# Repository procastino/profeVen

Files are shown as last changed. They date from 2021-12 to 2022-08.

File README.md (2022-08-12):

# profeVen
## What is this?
A little Arduino indicator for computer science class management. It must be placed on a visible spot on the student's table. It has an RGB LED and two pushbuttons, start and reset. When you press button start, led lights, indicating that the student needs the teacher (profe) to come (ven) and help him/her. Every while (1 minute by default), if the teacher has not attended the student demand, light will change color according to the sequence purple - cyan - blue - yellow - red, so that the teacher knows who has been waiting the most. When the light gets red, it stays there. When teacher solves the student's problem, presses reset button to turn light off. If the student has finished his work and wants to let the teacher know that he is ready to go on, he can long press the start button and a green light will start to fade out and in.
## (Not so) technicals
This device is controlled by an atTiny85, and powered by an USB connection. It has a custom PCB designed in KiCad and it's enclosure is designed in the openSCad files. The "lid" part must be printed with transparent or translucid plastic.
Programming is written in Arduino, surely it's not great code, but it gets the job done.
## Disclaimer
It is a quite overengineered solution for managing classrooms, you can obviously find simpler ways of dealing with your students doubts. But I teach design and technology, so... what did you expect?

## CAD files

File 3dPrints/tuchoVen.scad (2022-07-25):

//These are the pieces for a enclosure for the profeVen class management beacon. It's got a base, a lid and two buttons.

//parameters
side = 43.180;
roundCorner = 2.54;
screwHoleRadius = 1.5;
throughHoleRadius = 1.6;
wallThickness = 2;
baseHeight= 14;
$fn = 20;
buttonHoleRadius = 5;
pushButtonHeight = 5.5; //this is the height of the push Button, higher pcb buttons, shorter printed buttons.
xPosButtonHoleStart = 21.336;
yPosButtonHoleStart = 5.588;

xPosButtonHoleReset = 7.112;
yPosButtonHoleReset = 18.796;
connectorHole = 15.240;

//All the pieces/////
base();
translate ([side*1.6,0,0]) lid();
translate([0,side*1.5,0]) buttons();
//////////////

//base
//it's a difference between two rounded corner boxes plus some things
module base(){
    difference(){
        extBox();
        translate([0,0,wallThickness])pcbHole();
        //cable hole
        translate ([11,side,baseHeight-2.5]) cube([3,6,3]);
    }
    pcbStands();
    translate([-roundCorner*1.6,side/2,baseHeight/2])baseMountStands();
    translate([side+roundCorner*1.6,side/2,baseHeight/2])rotate([0,0,180]) baseMountStands();
}

//lid
//the same as the base, minus some things
module lid(){
    difference(){
        extBox();
        translate([0,0,wallThickness])pcbHole();
        //hole Button start
        translate([side-xPosButtonHoleStart,yPosButtonHoleStart,-1]) cylinder(r=buttonHoleRadius,h=4);
        //hole Button reset
        translate([side-xPosButtonHoleReset,yPosButtonHoleReset,-1]) cylinder(r=buttonHoleRadius,h=4);
        //hole connector
        translate ([-6,0,baseHeight-2.5]) cube([6,connectorHole,3]);
         //switch Hole
        translate ([side,side/1.5,baseHeight-5]) cube([6,9,6]);
    }
    //baseMount Stands
    translate([-roundCorner*1.6,side/2,baseHeight/2])baseMountStands();
    translate([side+roundCorner*1.6,side/2,baseHeight/2])rotate([0,0,180]) baseMountStands();

}





//button
//simple cylinders with symbols
module buttons(){
    //startButton
    difference(){
        union(){
            cylinder(r=buttonHoleRadius+wallThickness,h=baseHeight-wallThickness-pushButtonHeight);
            cylinder(r=buttonHoleRadius*0.9,h=baseHeight+wallThickness-pushButtonHeight);
            }
        translate([0,0,9]) cylinder(r=buttonHoleRadius/1.5,h=wallThickness,$fn=3);
     }
    //resetButton
   translate([30,0,0]) difference(){
        union(){
            cylinder(r=buttonHoleRadius+wallThickness,h=baseHeight-wallThickness-pushButtonHeight);
            cylinder(r=buttonHoleRadius*0.9,h=baseHeight+wallThickness-pushButtonHeight);
        }
        translate([0,0,9]) cylinder(r=buttonHoleRadius/1.5,h=wallThickness,$fn=4);
   }
}

//exterior box
module extBox(){
    hull(){
        cylinder (r=roundCorner+wallThickness, h = baseHeight);
        translate ([side,0,0]) cylinder (r=roundCorner+wallThickness, h = baseHeight);
        translate ([side,side,0]) cylinder (r=roundCorner+wallThickness, h = baseHeight);
        translate ([0,side,0]) cylinder (r=roundCorner+wallThickness, h = baseHeight);
    }
}

//pcb hole
module pcbHole(){
    hull(){
        cylinder (r=roundCorner, h = 16);
        translate ([side,0,0]) cylinder (r=roundCorner, h = 16);
        translate ([side,side,0]) cylinder (r=roundCorner, h = 16);
        translate ([0,side,0]) cylinder (r=roundCorner, h = 16);
    }
}

//pcb stands
module pcbStands(){
    difference(){
        translate([2.54,2.54,0])cylinder (r=roundCorner+wallThickness, h = baseHeight-1.7);
        translate([2.54,2.54,wallThickness]) cylinder (r=screwHoleRadius, h = baseHeight);
    }
    translate ([side,0,0]) cylinder (r=roundCorner+wallThickness, h = baseHeight-1.7);
    difference(){
        translate ([side-2.54,side-2.54,0]) cylinder (r=roundCorner+wallThickness, h = baseHeight-1.7);
        translate([side-2.54,side-2.54,wallThickness]) cylinder (r=screwHoleRadius, h = baseHeight);
    }
    translate ([0,side,0]) cylinder (r=roundCorner+wallThickness, h = baseHeight-1.7);
}
//base mount stands
module baseMountStands(){
    difference(){
        linear_extrude(height = baseHeight, center = true, convexity = 10, scale=[3.3,1])
        translate ([-1,0,0]) square([2,10],true);
        translate ([-3.6,0,baseHeight-8.8]) cylinder(r=throughHoleRadius,h=baseHeight);
        translate ([-3,0,-2]) cube([6,6,baseHeight],true);
}
}

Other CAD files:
3dPrints/tuchoVenLens.scad

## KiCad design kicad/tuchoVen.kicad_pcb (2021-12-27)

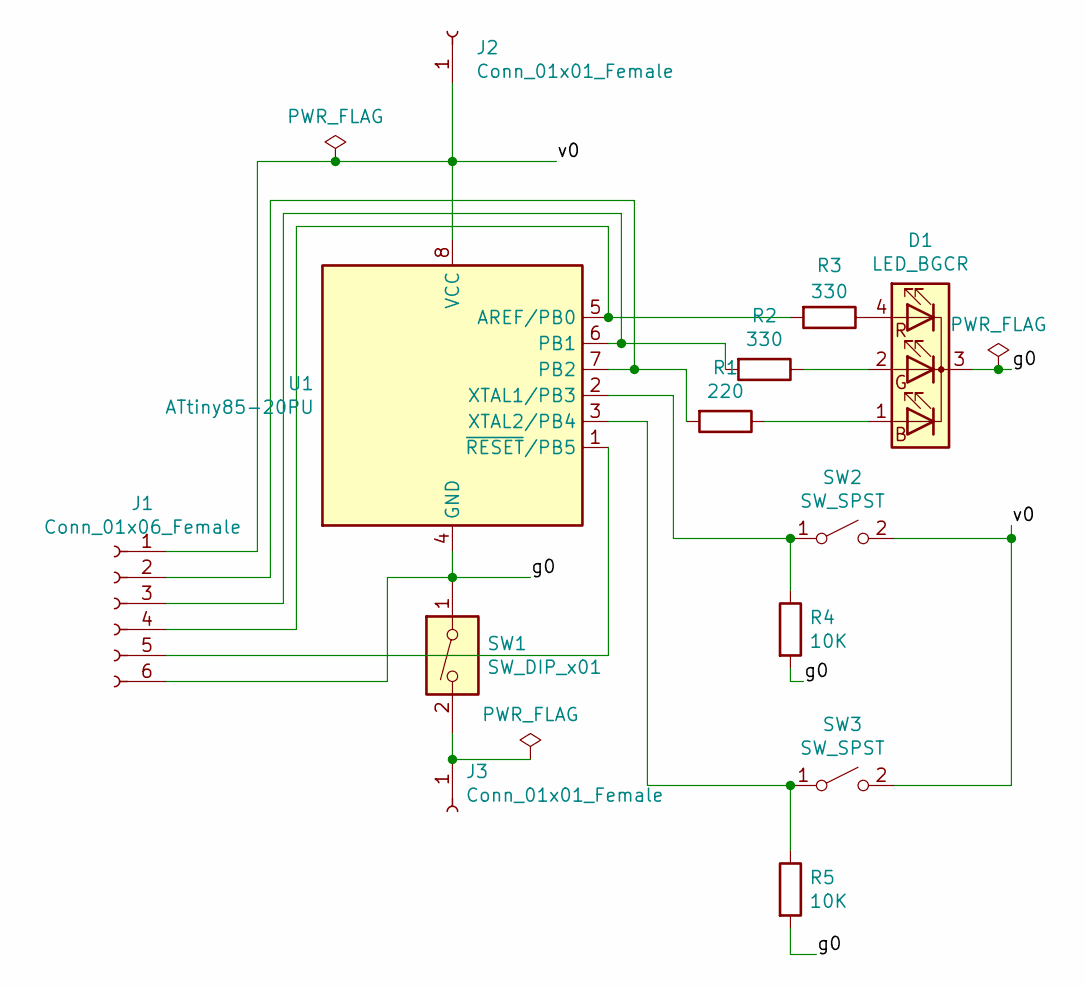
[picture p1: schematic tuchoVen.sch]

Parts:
D1: LED_BGCR; LED_D5.0mm-4_RGB
J1: Conn_01x06_Female; PinHeader_1x06_P2.54mm_Horizontal
J2, J3: Conn_01x01_Female; SolderWire-0.25sqmm_1x01_D0.65mm_OD1.7mm_Relief
R1: 220; R_Axial_DIN0207_L6.3mm_D2.5mm_P7.62mm_Horizontal
R2, R3: 330; R_Axial_DIN0207_L6.3mm_D2.5mm_P7.62mm_Horizontal
R4, R5: 10K; R_Axial_DIN0207_L6.3mm_D2.5mm_P7.62mm_Horizontal
SW1: SW_DIP_x01; SW_CuK_OS102011MA1QN1_SPDT_Angled
SW2, SW3: SW_SPST; SW_PUSH_6mm
U1: ATtiny85-20PU; DIP-8_W7.62mm

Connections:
/g0: D1.3 (K), J1.6, R4.2, R5.2, SW1.1, U1.4 (GND)
/v0: J1.1, J2.1, SW2.2 (B), SW3.2 (B), U1.8 (VCC)
unnamed: D1.1 (BA), R1.1
unnamed: D1.2 (GA), R2.1
unnamed: D1.4 (RA), R3.1
unnamed: J1.2, R1.2, U1.7 (PB2)
unnamed: J1.3, R2.2, U1.6 (PB1)
unnamed: J1.4, R3.2, U1.5 (AREF/PB0)
unnamed: J1.5, U1.1 (~RESET~/PB5)
unnamed: J3.1, SW1.2
unnamed: R4.1, SW2.1 (A), U1.2 (XTAL1/PB3)
unnamed: R5.1, SW3.1 (A), U1.3 (XTAL2/PB4)

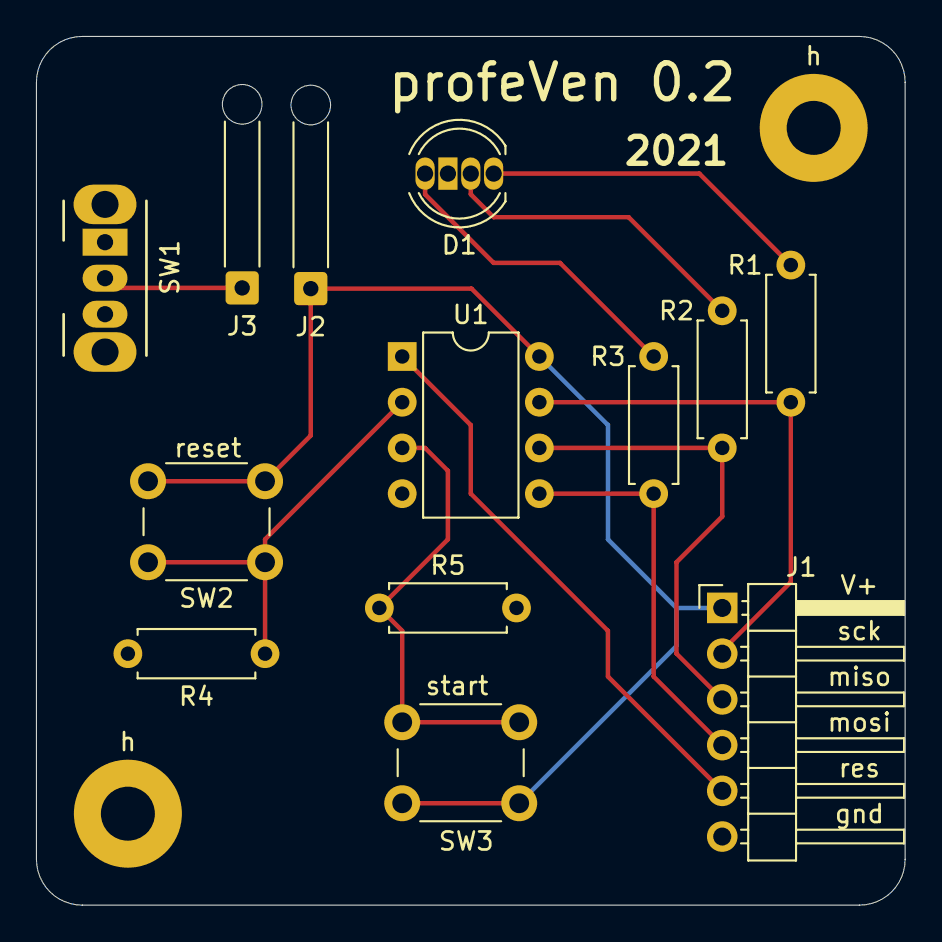
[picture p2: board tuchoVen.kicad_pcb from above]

Board: 2 copper layers, 48.3 x 48.3 mm, 15 parts (0 on the bottom side), 12 nets.

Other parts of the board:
h: MountingHole_3mm_Pad
h#2: MountingHole_3mm_Pad

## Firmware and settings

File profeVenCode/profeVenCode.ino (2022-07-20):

/*proxecto dun dispositivo para chamar ao profesor, para situar enriba do ordenador.
 * cando o alumno preme o botón, acéndese a luz de chamada, que vai cambiando en función do tempo
 * que leva agardando. A luz apágase premendo o botón de reset.
 * Codigo feito para un Attiny85 cun LED RGB con cátodo común, cambiar a lóxica se é de ánodo común en changelight().
 * Ollo, programar co reloxo interno de 1MHz para que os tempo sexan reais
 */

//pins para os leds de cores, dacordo coa PCB do proxecto.
const int pinR = 0;
const int pinG = 1;
const int pinB = 2;
//pins para os botons de reseteo e de chamada
const int buttonReset = 3; //pin 2 fisico
const int buttonStart = 4; //pin 3 fisico
//variables precisas para a xestión do tempo e recollida de estado dos botóns
bool resetState;
bool resetLastState = LOW;
bool startState;
bool startLastState = LOW;
long timeElapsed;
long timeChange = 60000; //cada cantos milisegundos cambia de cor a luz
bool calling = false; //esta chamando o alumno?
bool finished = false; //acabou o traballo o alumno?
int val;
int increment = 1;
int byteLeds = 7; //numero binario que define o estado dos leds 
//secuencia de cores para a funcion de chamado
int colorSequence[] = {2,6,4,1,3}; //purple, blue, cyan, yellow, red
int colorIndex; //valor para seleccionar un elemento da secuencia de cores
int longPressDuration = 2000; //duracion da pulsacion longa
long pressedTime;


void setup() {
  //Modo dos pines
  pinMode (pinR, OUTPUT);
  pinMode (pinG, OUTPUT);
  pinMode (pinB, OUTPUT);
  pinMode (buttonReset, INPUT);
  pinMode (buttonStart, INPUT);
  //actualizamos o estado dos leds
  changeLight();

}

void loop() {
  //lemos boton de reset, apagamos todo se se activou
  resetState = digitalRead(buttonReset);
  if (resetState != resetLastState){
    if (resetState == HIGH){
      byteLeds = 7;//isto define todos os leds como apagados
      changeLight();
      calling = false;
      finished = false;
      resetLastState = HIGH;
    }
    else {
      resetLastState = LOW;
    }
  }

  //lemos boton de start, poñemos en marcha a chamada se se activou
  startState = digitalRead(buttonStart);
  if (startState != startLastState){
    if (startState == HIGH){
      pressedTime = millis();//inciamos o temporizador do intre de pulsacion
      timeElapsed = millis(); //iniciamos o temporizador de tempo transcorrido
      calling = true; //o chamador está a chamar
      finished = false; //non rematou
      colorIndex = 0;
      byteLeds = colorSequence[colorIndex]; // isto debera acender purple
      changeLight();
      startLastState = HIGH;
    }
    else {
      //ao soltar o boton de start comprobamos se foi pulsacion longa
      long releasedTime = millis();
      long pressedElapsed = releasedTime - pressedTime;
      //se foi pulsacion longa activamos a secuencia de finished
      if (pressedElapsed > longPressDuration){
        calling = false;
        finished = true;
        byteLeds = 7;
        changeLight();
        val = 0;
        }
      startLastState = LOW;
    }
  }
 
  //se estamos chamando, comprobamos timer e acendemos en consecuencia
  if (calling) {
    if ((millis() - timeElapsed) > timeChange){
      if(colorIndex < 4){
        colorIndex++;
        byteLeds = colorSequence[colorIndex];
        changeLight();
      }
      timeElapsed = millis();
    }
  }
  // se temos rematado activamos a secuencia finished
  if (finished){
    analogWrite(pinG,val);
    val+=increment;
    if (val <= 0 || val >= 255) {
      increment = -increment;
      }
    delay(7);
  }
}

//esta funcion activa os leds segundo o valor de byteLeds
//if LED is common anode, comment out the ^1's
void changeLight() {
  digitalWrite(pinB, bitRead(byteLeds,0)^1);
  digitalWrite(pinG, bitRead(byteLeds,1)^1);
  digitalWrite(pinR, bitRead(byteLeds,2)^1);
}

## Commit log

2021-12-27 added boards
    [tuchoVen-B_Cu.gbr, tuchoVen-B_Mask.gbr, tuchoVen-B_SilkS.gbr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]
2022-07-12 comments added
    [tuchoVen.scad, tuchoVenBase.stl, tuchoVenBoton.stl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]
